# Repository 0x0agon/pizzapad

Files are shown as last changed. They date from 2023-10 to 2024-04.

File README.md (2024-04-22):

# pizzapad

## What is pizzapad?
pizzapad is a 5 key macropad with encoder and rgb led support inspired by Stellar Pizza's flaming pizza logo!

## How can I build one?
### Create the PCB
The latest gerbers files are included in the "gerber" folder. These can be used to order pcb's from your favorite pcb manufacturer, such as [JLCPCB](https://jlcpcb.com/)

### Buy and Solder parts

To build a pizzapad you'll need

|Part|Quantity|Digikey #|Manufactuer #|
|---|---|---|---|
|Pcb|1|N/A|N/A|
|cherryMX compatible switches|5|N/A|N/A|
|cherryMX compatible hotswap sockets|5|N/A|N/A|
|promicro compatible microcontroller|1|N/A|N/A|
|reset switch|1|B3U-1000P|SW1020CT-ND|
|rotary encoder|1|PEC11R-4215F-S0024|PEC11R-4215F-S0024-ND|
|addressable led|5|4684|1528-4684-ND|
|diode|5|1N4148WX-TP|1N4148WX-TPMSCT-ND|
|10K ohm resistor|2|RMCF0805JT10k0|RMCF0805JT10k0CT-ND|

### Install firmware
pizzapad's firmware is based on The [QMK Project](https://github.com/qmk/qmk_firmware)

1) Download the base QMK firmware following the instructions on QMK's github page
2) Create a folder called `pizzapad` in `qmk_firmware/keyboards`
3) Build the firmware according to QMK's build instructions, pointing it to the `pizzapad` keyboard folder.
4) Profit!

#### Default key layout
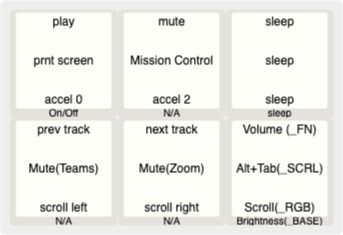
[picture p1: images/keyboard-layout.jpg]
Default layout
  
The default has 4 layers.  
Switch layers by pressing the encoder in.
##### Layer 1 - Media [Gold]
This layer focuses on media controls, with the encoder controlling volume

##### Layer 2 - FN [Red]
This layer focuses on some hopefully useful shortcuts. The encoder switches between active windows (simulates alt-tab)

##### Layer 3 - Scroll [Magenta]
This layer brings scrolling to the macropad. The encoder controls scrolling vertically, and buttons 4 + 5 control horizontal scrolling

##### Layer 4 - RGB [Teal]
This layer controls the rgb indicator lights. The encoder turns brightness up and down. This layer isn't fully functional yet, but brightness controls should work.

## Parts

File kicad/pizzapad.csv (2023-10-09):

Source: | /Users/b/workspace/personal/keyboards/pizzapad/pizzapad.kicad_sch
Date: | Sunday, August 20, 2023 at 08:43:39 PM
Tool: | Eeschema (6.0.1-0)
Generator: | /Applications/KiCad/KiCad.app/Contents/SharedSupport/plugins/bom_csv_grouped_by_value.py
Component Count: | 20
Individual Components:
Item | Qty | Reference(s) | Value | LibPart | Footprint | Datasheet
 |  | B1 | SPARKFUN_PRO_MICRO | sparkfun_pro_micro:SPARKFUN_PRO_MICRO | kbd:ProMicro_v3.5
 |  | D0 | 1N4148WT | Diode:1N4148WT | Diode_SMD:D_SOD-523 | https://www.diodes.com/assets/Datasheets/ds30396.pdf
 |  | D1 | 1N4148WT | Diode:1N4148WT | Diode_SMD:D_SOD-523 | https://www.diodes.com/assets/Datasheets/ds30396.pdf
 |  | D2 | 1N4148WT | Diode:1N4148WT | Diode_SMD:D_SOD-523 | https://www.diodes.com/assets/Datasheets/ds30396.pdf
 |  | D3 | 1N4148WT | Diode:1N4148WT | Diode_SMD:D_SOD-523 | https://www.diodes.com/assets/Datasheets/ds30396.pdf
 |  | D4 | 1N4148WT | Diode:1N4148WT | Diode_SMD:D_SOD-523 | https://www.diodes.com/assets/Datasheets/ds30396.pdf
 |  | D5 | 1N4148WT | Diode:1N4148WT | Diode_SMD:D_SOD-523 | https://www.diodes.com/assets/Datasheets/ds30396.pdf
 |  | LED0 | SK6812MINI_1 | sk6812mini_1:SK6812MINI_1 | pizzapad:LED_SK6812MINI_PLCC4_3.5x3.5mm_P1.75mm | https://cdn-shop.adafruit.com/product-files/2686/SK6812MINI_REV.01-1-2.pdf
 |  | LED1 | SK6812MINI_1 | sk6812mini_1:SK6812MINI_1 | pizzapad:LED_SK6812MINI_PLCC4_3.5x3.5mm_P1.75mm | https://cdn-shop.adafruit.com/product-files/2686/SK6812MINI_REV.01-1-2.pdf
 |  | LED2 | SK6812MINI_1 | sk6812mini_1:SK6812MINI_1 | pizzapad:LED_SK6812MINI_PLCC4_3.5x3.5mm_P1.75mm | https://cdn-shop.adafruit.com/product-files/2686/SK6812MINI_REV.01-1-2.pdf
 |  | LED3 | SK6812MINI_1 | sk6812mini_1:SK6812MINI_1 | pizzapad:LED_SK6812MINI_PLCC4_3.5x3.5mm_P1.75mm | https://cdn-shop.adafruit.com/product-files/2686/SK6812MINI_REV.01-1-2.pdf
 |  | LED4 | SK6812MINI_1 | sk6812mini_1:SK6812MINI_1 | pizzapad:LED_SK6812MINI_PLCC4_3.5x3.5mm_P1.75mm | https://cdn-shop.adafruit.com/product-files/2686/SK6812MINI_REV.01-1-2.pdf
 |  | LED5 | SK6812MINI_1 | sk6812mini_1:SK6812MINI_1 | pizzapad:LED_SK6812MINI_PLCC4_3.5x3.5mm_P1.75mm | https://cdn-shop.adafruit.com/product-files/2686/SK6812MINI_REV.01-1-2.pdf
 |  | RE_3_1 | CHERRY-MX-ENCODER | cherry-mx-encoder:CHERRY-MX-ENCODER | pizzapad:RotaryEncoder_Alps_EC11E-Switch_Vertical_H20mm
 |  | S0 | MOMENTARY-SWITCH-SPST-LED-PTH-CHERRY | momentary-switch-spst-led-pth-cherry:MOMENTARY-SWITCH-SPST-LED-PTH-CHERRY | pizzapad:Kailh-CPG151101S11_MX_Socket-1.00u
 |  | S1 | MOMENTARY-SWITCH-SPST-LED-PTH-CHERRY | momentary-switch-spst-led-pth-cherry:MOMENTARY-SWITCH-SPST-LED-PTH-CHERRY | pizzapad:Kailh-CPG151101S11_MX_Socket-1.00u
 |  | S2 | MOMENTARY-SWITCH-SPST-LED-PTH-CHERRY | momentary-switch-spst-led-pth-cherry:MOMENTARY-SWITCH-SPST-LED-PTH-CHERRY | pizzapad:Kailh-CPG151101S11_MX_Socket-1.00u
 |  | S3 | MOMENTARY-SWITCH-SPST-LED-PTH-CHERRY | momentary-switch-spst-led-pth-cherry:MOMENTARY-SWITCH-SPST-LED-PTH-CHERRY | pizzapad:Kailh-CPG151101S11_MX_Socket-1.00u
 |  | S4 | MOMENTARY-SWITCH-SPST-LED-PTH-CHERRY | momentary-switch-spst-led-pth-cherry:MOMENTARY-SWITCH-SPST-LED-PTH-CHERRY | pizzapad:Kailh-CPG151101S11_MX_Socket-1.00u
 |  | SW1 | SW_SPST | Switch:SW_SPST |  | ~
Collated Components:
Item | Qty | Reference(s) | Value | LibPart | Footprint | Datasheet
1 | 1 | B1 | SPARKFUN_PRO_MICRO | sparkfun_pro_micro:SPARKFUN_PRO_MICRO | kbd:ProMicro_v3.5
2 | 6 | D0, D1, D2, D3, D4, D5 | 1N4148WT | Diode:1N4148WT | Diode_SMD:D_SOD-523 | https://www.diodes.com/assets/Datasheets/ds30396.pdf
3 | 6 | LED0, LED1, LED2, LED3, LED4, LED5 | SK6812MINI_1 | sk6812mini_1:SK6812MINI_1 | pizzapad:LED_SK6812MINI_PLCC4_3.5x3.5mm_P1.75mm | https://cdn-shop.adafruit.com/product-files/2686/SK6812MINI_REV.01-1-2.pdf
4 | 1 | RE_3_1 | CHERRY-MX-ENCODER | cherry-mx-encoder:CHERRY-MX-ENCODER | pizzapad:RotaryEncoder_Alps_EC11E-Switch_Vertical_H20mm
5 | 5 | S0, S1, S2, S3, S4 | MOMENTARY-SWITCH-SPST-LED-PTH-CHERRY | momentary-switch-spst-led-pth-cherry:MOMENTARY-SWITCH-SPST-LED-PTH-CHERRY | pizzapad:Kailh-CPG151101S11_MX_Socket-1.00u
6 | 1 | SW1 | SW_SPST | Switch:SW_SPST |  | ~

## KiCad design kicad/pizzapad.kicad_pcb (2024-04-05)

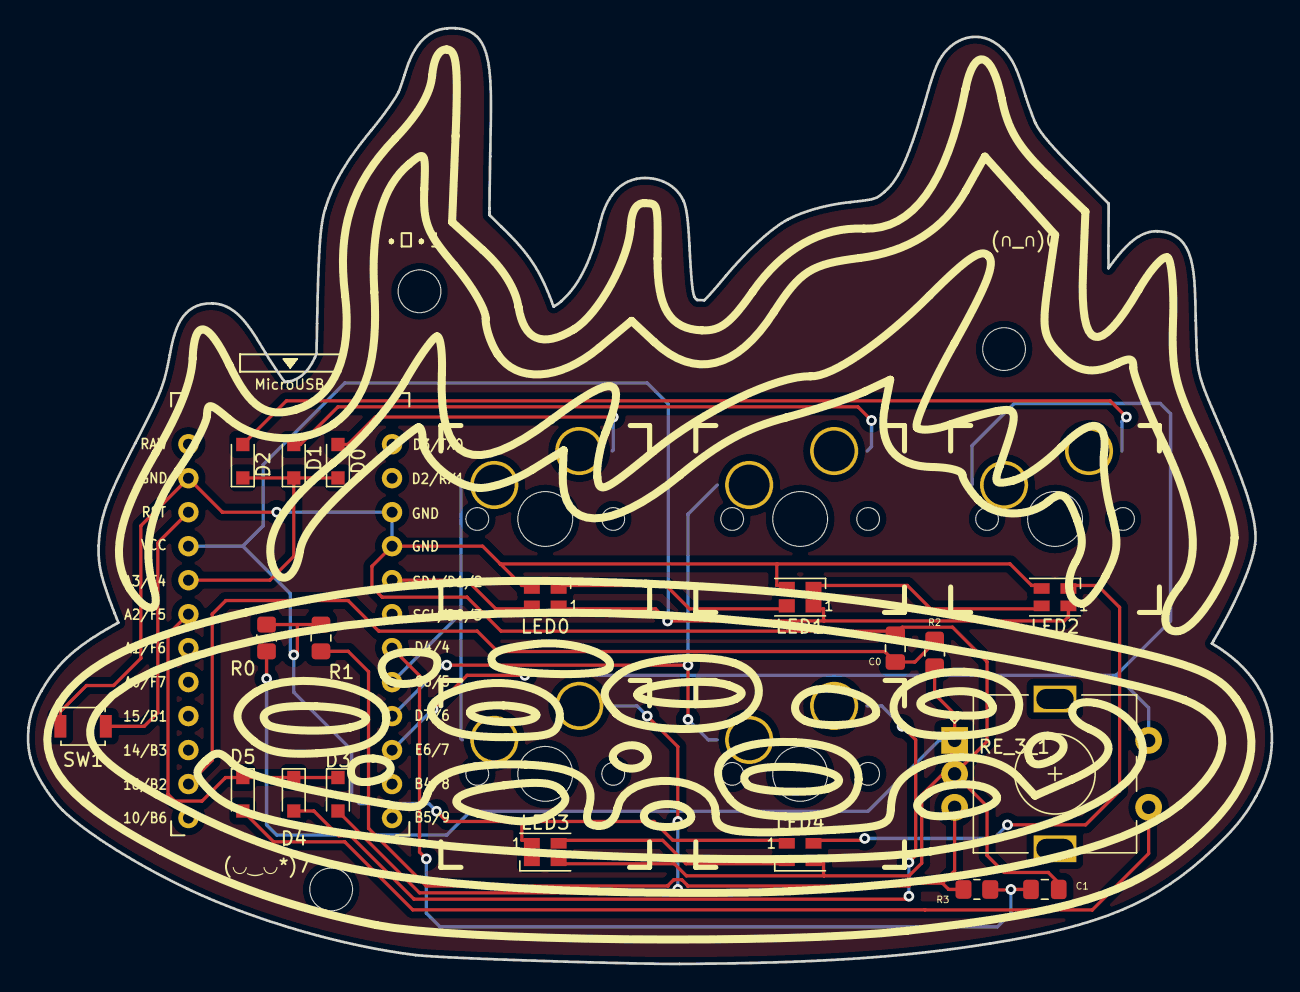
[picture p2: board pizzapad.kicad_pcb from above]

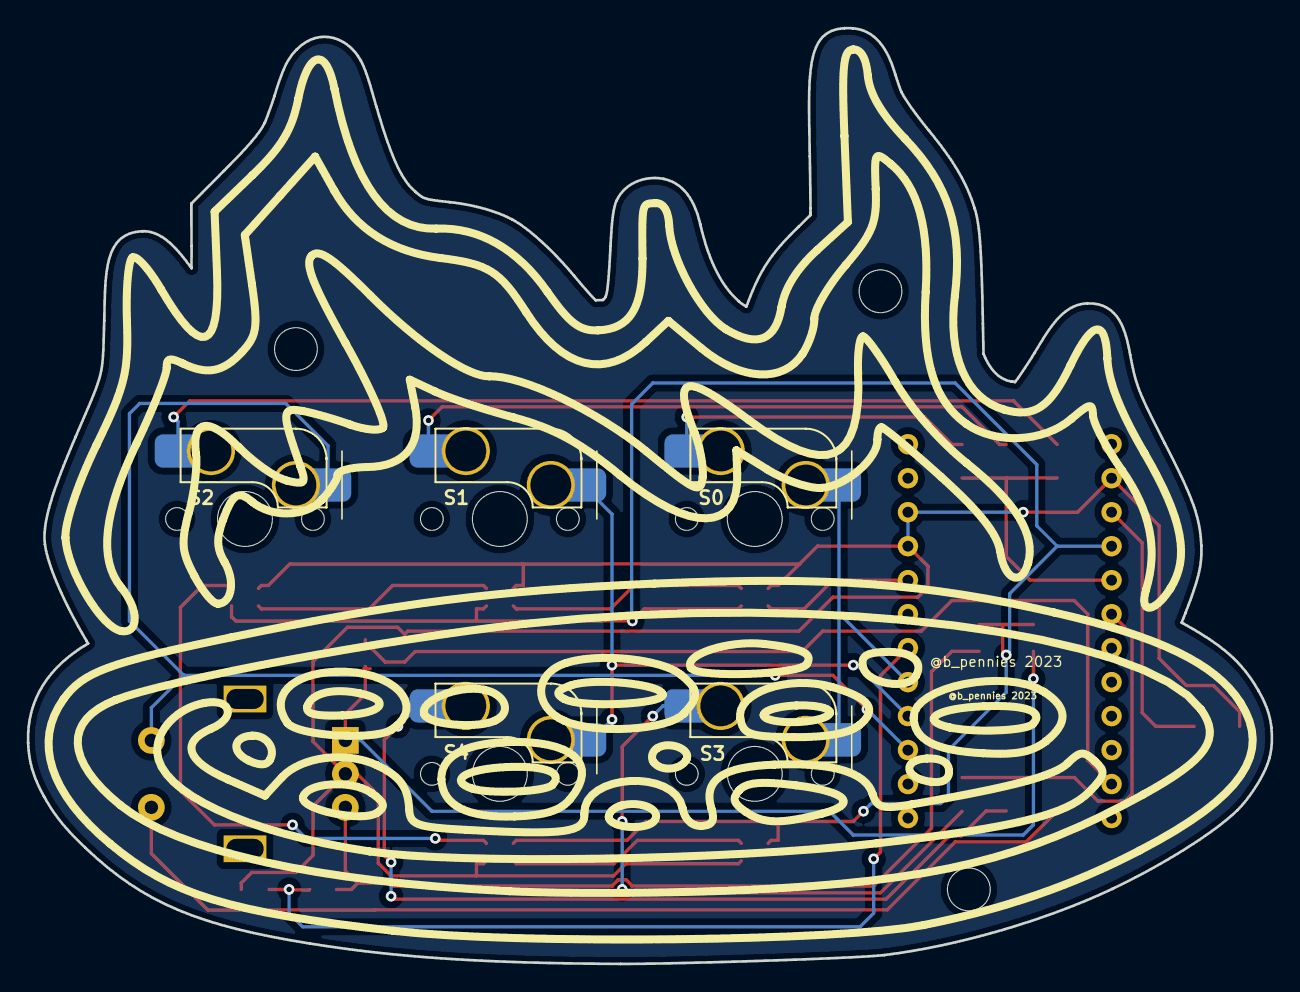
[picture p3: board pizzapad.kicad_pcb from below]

Board: 2 copper layers, 93.0 x 69.9 mm, 28 parts (5 on the bottom side), 23 nets.

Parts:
(∩_∩)0: _; MountingHole_3.2mm_M3_ISO7380
(◡‿◡*)7: _; MountingHole_3.2mm_M3_ISO7380
B1: SPARKFUN_PRO_MICRO; ProMicro_v3.5
C0, C1: Filter C0.01uF; C_0805_2012Metric_Pad1.18x1.45mm_HandSolder
D0, D1, D2, D3, D4, D5: 1N4148WT; D_SOD-323_HandSoldering
LED0, LED1, LED2, LED3, LED4: SK6812MINI_1; LED_SK6805_PLCC4_2.4x2.7mm_P1.3mm
R0, R1: Pull up R10k; R_0805_2012Metric_Pad1.20x1.40mm_HandSolder
R2, R3: Filter R10k; R_0805_2012Metric_Pad1.20x1.40mm_HandSolder
RE_3_1: Encoder; RotaryEncoder_Alps_EC11E-Switch_Vertical_H20mm
S0, S1, S2, S3, S4: Cherry MX Switch; Kailh-CPG151101S11_MX_Socket-1.00u
SW1: SW_SPST; SW_SPST_B3U-1000P
•ᴥ•1: _; MountingHole_3.2mm_M3_ISO7380

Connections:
/COL0: B1.8 (*5), S0.S2 (2), S3.S2 (2)
/COL1: B1.9 (*6), S1.S2 (2), S4.S2 (2)
/COL2: B1.10 (7), RE_3_1.S2 (2), S2.S2 (2)
/ENCODER0_L0: B1.14 (11(MOSI)), C0.2, R2.1
/ENCODER0_L1: B1.7 (4), C1.2, R3.2
/KEY_LEDS: B1.5 (2), LED0.4 (DIN)
/RESET: B1.22 (RESET), SW1.1 (A)
/ROW0: B1.20 (A3), D0.1 (K), D1.1 (K), D2.1 (K)
/ROW1: B1.19 (A2), D3.1 (K), D4.1 (K), D5.1 (K)
GND: B1.3 (GND@1), B1.4 (GND), B1.23 (GND@2), C0.1, C1.1, LED0.3 (VSS), LED1.3 (VSS), LED2.3 (VSS), LED3.3 (VSS), LED4.3 (VSS), RE_3_1.C, SW1.2 (B)
unnamed: D0.2 (A), S0.S1 (1)
unnamed: D1.2 (A), S1.S1 (1)
unnamed: D2.2 (A), S2.S1 (1)
unnamed: D3.2 (A), S3.S1 (1)
unnamed: D4.2 (A), S4.S1 (1)
unnamed: D5.2 (A), RE_3_1.S1 (1)
unnamed: LED0.2 (DOUT), LED1.4 (DIN)
unnamed: LED1.2 (DOUT), LED2.4 (DIN)
unnamed: LED2.2 (DOUT), LED4.4 (DIN)
unnamed: LED3.4 (DIN), LED4.2 (DOUT)
unnamed: R0.2, R2.2, RE_3_1.A
unnamed: R1.1, R3.1, RE_3_1.B
VCC: B1.21 (VCC), LED0.1 (VDD), LED1.1 (VDD), LED2.1 (VDD), LED3.1 (VDD), LED4.1 (VDD), R0.1, R1.2

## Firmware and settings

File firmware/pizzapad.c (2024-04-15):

/* Copyright 2022 imchipwood && deveth0
 *
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
 * You should have received a copy of the GNU General Public License
 * along with this program.  If not, see <http://www.gnu.org/licenses/>.
 */

#include "quantum.h"

#ifdef RGB_MATRIX_ENABLE
led_config_t g_led_config = {{// Key Matrix to LED Index
                              {0, 1, 2},
                              {3, 4, 5,}},
                             {// LED Index to Physical Position
                              {0, 0},
                              {75, 0},
                              {149, 0},

                              {224, 0},
                              {224, 21},
                              {149, 21}},
                             {// LED Index to Flag
                              4, 4, 4, 4, 4, 4}};
#endif

void keyboard_pre_init_kb(void) {
    // Set LED IO as outputs
    // setPinOutput(LED_00);

    // Set the encoder A pin (B2) to input with pull-up resistor
//    DDRB &= ~(1<<2);
//    PORTB &= ~(1<<2);
//
//    // Set the encoder B pin (D4) to input with pull-up resistor
//    DDRD &= ~(1<<4);
//    PORTD &= ~(1<<4);  // disable the pull up for testing

    keyboard_pre_init_user();
}

//void shutdown_user(void) {
    // Shutdown LEDs
    // writePinLow(LED_00);
//}

// layer_state_t layer_state_set_kb(layer_state_t state) {
//     // Layer LEDs act as binary indication of current layer
//     uint8_t layer = get_highest_layer(state);
//     writePin(LED_00, layer & 0b1);
//     writePin(LED_01, (layer >> 1) & 0b1);
//     uprintf("%d string", layer);
//     return layer_state_set_user(state);
// }

// Optional override functions below.
// You can leave any or all of these undefined.
// These are only required if you want to perform custom actions.

void matrix_init_kb(void) {
    // put your keyboard start-up code here
    // runs once when the firmware starts up
    // uint8_t led_delay_ms = 80;
    // for (int i = 0; i < 2; i++) {
    //     writePinHigh(LED_00);
    //     wait_ms(led_delay_ms);
    //     writePinLow(LED_00);
    //     if (i < 1) {
    //         wait_ms(led_delay_ms);
    //     }
    // }

    matrix_init_user();
}

//void keyboard_post_init_user(void) {
//    debug_enable=true;
//    debug_matrix=true;
//    debug_keyboard=true;
//}

// bool led_update_kb(led_t led_state) {
//     if (!led_update_user(led_state)) return false;
//     // put your keyboard LED indicator (ex: Caps Lock LED) toggling code here
//     writePin(LED_01, !led_state.num_lock);
//     return true;
// }
bool encoder_update_kb(uint8_t index, bool clockwise) {
    uprintf("Encoder time!\n");
    if (!encoder_update_user(index, clockwise)) {
        uprintf("returning \n");
        return false; /* Don't process further events if user function exists and returns false */
    }
    if (index == 0) { /* First encoder */
        if (clockwise) {
            // tap_code(KC_VOLU);
            uprintf("Encoder CW\n");
            tap_code(KC_SLSH);
        } else {
            // tap_code(KC_VOLD);
            uprintf("Encoder CCW\n");
            tap_code(KC_BSLS);
        }
    } else if (index == 1) { /* Second encoder */
	    // ignore this
        // if (clockwise) {
        //     // tap_code(KC_VOLU);
        //     uprintf("Encoder CW\n");
        //     tap_code(KC_SLSH);
        // } else {
        //     // tap_code(KC_VOLD);
        //     uprintf("Encoder CCW\n");
        //     tap_code(KC_BSLS);
        // }
	
    }
    return true;
}

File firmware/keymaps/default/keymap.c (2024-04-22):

/*
Copyright 2022 imchipwood && deveth0

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
You should have received a copy of the GNU General Public License
along with this program.  If not, see <http://www.gnu.org/licenses/>.
*/

#include QMK_KEYBOARD_H
#include "print.h"

enum layer_names {
    _MDIA,
    _FN,
    _SCRL,
    _RGB
};

// clang-format off
const uint16_t PROGMEM keymaps[][MATRIX_ROWS][MATRIX_COLS] = {
    /*
            MDIA LAYER - Media
    /-------------------------------------------`
    |             | Play/Pause |    Mute    |   Sleep   |
    |             |------------|------------|-----------|
    |             | Prv Track  | Next Track | FN layer |
    \-------------------------------------------'
    */
    [_MDIA] = LAYOUT(
                    KC_MPLY,      KC_MUTE,    KC_SLEP,
                    KC_MPRV,      KC_MNXT,    TO(_FN)
    ),
    /*
            SUB LAYER  - FN controls, Modes on encoder
    /-------------------------------------------`
    |             | Print Screen  | Mission Control |    Sleep    |
    |             |---------------|-----------------|-------------|
    |             |  Teams Mute   |    Zoom Mute    |  SCRL layer |
    \-------------------------------------------'
    */
    [_FN] = LAYOUT(
                    LCTL(LSFT(LGUI(KC_P4))),   KC_MCTL ,     KC_SLEP,
                    LCTL(LSFT(KC_M)),     LSFT(LGUI(KC_A)),    TO(_SCRL)
                    // KC_P6,      KC_P7,    KC_P8,
                    // KC_P9,      KC_P0,    TO(0)
    ),
    /*
            SUB LAYER  - SCRL controls, scrolling
    /-------------------------------------------`
    |             | Speed 0  | Speed 2 | Sleep |
    |             |---------|---------|---------|
    |             | Sroll Left | Scroll Right | RGB Layer |
    \-------------------------------------------'
    */
    [_SCRL] = LAYOUT(
                    KC_ACL0,    KC_ACL2,     KC_SLEP,
                    KC_WH_R,     KC_WH_L,    TO(_RGB)
                    // KC_P6,      KC_P7,    KC_P8,
                    // KC_P9,      KC_P0,    TO(0)
    ),
    /*
            SUB LAYER  - RGB controls, Modes on encoder
    /-------------------------------------------`
    |             | On/Off  | No Anim | Sleep |
    |             |---------|---------|---------|
    |             | Twinkle |  Breathe |  MDIA Layer |
    \-------------------------------------------'
    */
    [_RGB] = LAYOUT(
                    RGB_TOG,    RGB_M_P,     KC_SLEP,
                    RGB_M_TW,     RGB_M_B,    TO(_MDIA)
                    // KC_P6,      KC_P7,    KC_P8,
                    // KC_P9,      KC_P0,    TO(0)
    ),
};
// clang-format on

// encoder mapping
#if defined(ENCODER_MAP_ENABLE)
const uint16_t PROGMEM encoder_map[][NUM_ENCODERS][NUM_DIRECTIONS] = {
    [_MDIA] = { ENCODER_CCW_CW(KC_VOLD, KC_VOLU) },
    [_FN] = { ENCODER_CCW_CW(LGUI(KC_TAB), LSFT(LGUI(KC_TAB))) },
    [_SCRL] = { ENCODER_CCW_CW(KC_WH_D, KC_WH_U)},
    [_RGB] = { ENCODER_CCW_CW(RGB_VAD, RGB_VAI) },
};
#endif

// define rgb light layers
const rgblight_segment_t PROGMEM layer1[] = RGBLIGHT_LAYER_SEGMENTS(
    {0, 5, HSV_GOLD}
);
const rgblight_segment_t PROGMEM layer2[] = RGBLIGHT_LAYER_SEGMENTS(
    {0, 5, HSV_RED}
);
const rgblight_segment_t PROGMEM layer3[] = RGBLIGHT_LAYER_SEGMENTS(
    {0, 5, HSV_MAGENTA}
);
const rgblight_segment_t PROGMEM layer4[] = RGBLIGHT_LAYER_SEGMENTS(
    {0, 5, HSV_TEAL}
);

// Now define the array of layers. Later layers take precedence
const rgblight_segment_t* const PROGMEM custom_rgb_layers[] = RGBLIGHT_LAYERS_LIST(
    layer1,
    layer2,
    layer3,
    layer4

);

void keyboard_post_init_user(void) {
    debug_enable=true;
    debug_matrix=true;
    debug_keyboard=true;
    // Enable the LED layers
    rgblight_layers = custom_rgb_layers;
}

// now the code for actually updating the rgb light layers
layer_state_t layer_state_set_user(layer_state_t state) {
    layer_state_t highest_layer = get_highest_layer(state);
    rgblight_set_layer_state(0, highest_layer == _MDIA);
    rgblight_set_layer_state(1, highest_layer == _FN);
    rgblight_set_layer_state(2, highest_layer == _SCRL);
    rgblight_set_layer_state(3, highest_layer == _RGB);
    switch (highest_layer) {
    case _RGB:
        rgblight_mode(2);
    }

    return state;
}

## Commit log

2023-10-09 Initial commit of V2 pizzapad and v1 pizzapad-base
    [pizzapad-B_Cu.gbr, pizzapad-B_Mask.gbr, pizzapad-B_Paste.gbr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]
2024-04-05 restructuring repo, cleaning up
    [pizzapad-B_Cu.gbr, pizzapad-B_Mask.gbr, pizzapad-B_Paste.gbr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]
2024-04-08 Update rgb to change on layer switch

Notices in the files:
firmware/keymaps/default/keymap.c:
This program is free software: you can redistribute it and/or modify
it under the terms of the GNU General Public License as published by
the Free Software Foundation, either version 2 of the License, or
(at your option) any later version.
